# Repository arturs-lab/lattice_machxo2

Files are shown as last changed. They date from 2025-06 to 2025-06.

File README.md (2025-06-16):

# lattice_machxo2
lattice machxo2 256 breakout board

## Power Supply
All four VIO circuits are connected to 3V3 by traces on bottom of the board. 
In this configuration you do not have to populate VIO jumpers, voltaage regulator nor its capacitors.
If you want to use different VIO, cut corresponding trace(s), install jumper(s) and 
VIO voltage regulator and caps.

The 1Ohm resistors on the bottom of the board can be used to measure current draw of IO sections by 
measuring voltage drop on resistors. 0Ohm jumpers can also be installed.

## Oscillator
To use on-board oscillator, install it and jumper pin OSC to CLK.
To use off-board clock source, connect it between CLK and GND pins. 
In this case on-board oscillator does not have to be installed.

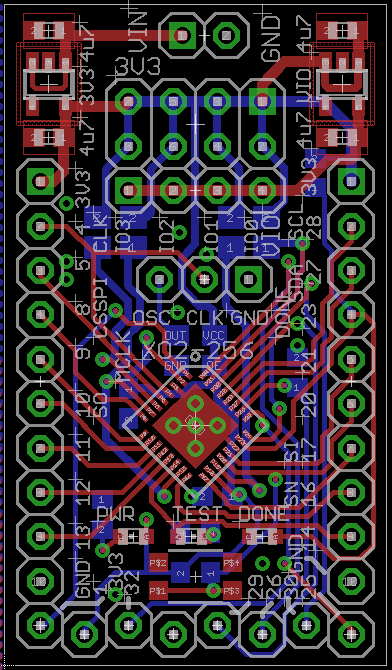
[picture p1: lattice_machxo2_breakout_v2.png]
pcb


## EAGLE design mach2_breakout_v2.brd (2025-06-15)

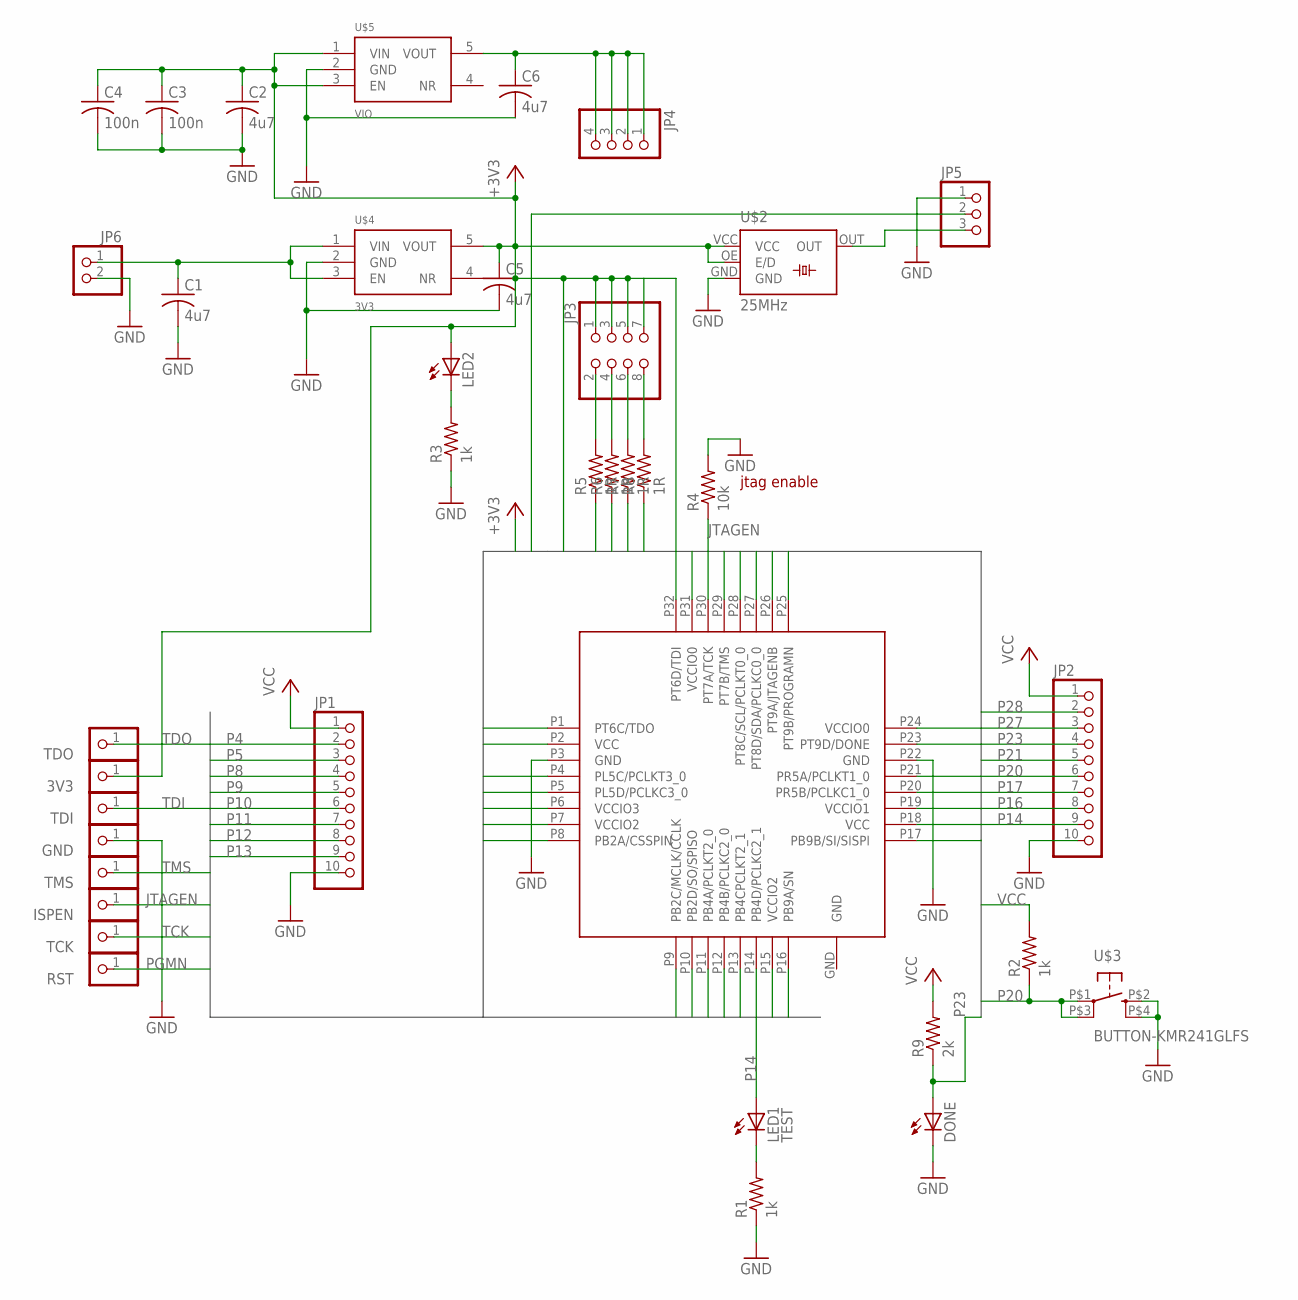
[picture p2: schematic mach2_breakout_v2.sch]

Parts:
3V3: PINHD-1X1; 1X01
C1, C2, C5, C6: 4u7; C0603
C3, C4: 100n; C0603
DONE: LEDCHIPLED_0603; CHIPLED_0603
GND: PINHD-1X1; 1X01
ISPEN: PINHD-1X1; 1X01
JP1, JP2: PINHD-1X10; 1X10
JP3: PINHD-2X4V; 2X04
JP4: PINHD-1X4; 1X04
JP5: PINHD-1X3; 1X03
JP6: PINHD-1X2; 1X02
LED1: TEST; CHIPLED_0603
LED2: LEDCHIPLED_0603; CHIPLED_0603
R1, R2, R3: 1k; R0603
R4: 10k; R0603
R5, R6, R7, R8: 1R; R0805
R9: 2k; R0603
RST: PINHD-1X1; 1X01
TCK: PINHD-1X1; 1X01
TDI: PINHD-1X1; 1X01
TDO: PINHD-1X1; 1X01
TMS: PINHD-1X1; 1X01
U$1: XO2-256; QFN32
U$2: 25MHz; FXO_3225
U$3: BUTTON-KMR241GLFS; PUSHBUTTON-KMR241GLFS
U$4: 3V3; SOT23-5
U$5: VIO; SOT23-5

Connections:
GND: C1.2, C2.2, C3.2, C4.2, C5.2, C6.2, DONE.C, GND.1, JP1.10, JP2.10, JP5.1, JP6.2, R1.1, R3.1, R4.2, U$1.P3 (GND), U$1.P22 (GND), U$2.GND, U$3.P$2 (2), U$3.P$4 (4), U$4.2 (GND), U$5.2 (GND)
JTAGEN: ISPEN.1, R4.1, U$1.P26 (PT9A/JTAGENB)
unnamed: C1.1, JP6.1, U$4.1 (VIN), U$4.3 (EN)
unnamed: JP5.3, U$2.OUT
unnamed: LED1.C, R1.2
unnamed: JP3.8, R8.2
unnamed: LED2.C, R3.2
unnamed: C6.1, JP4.1, JP4.2, JP4.3, JP4.4, U$5.5 (VOUT)
unnamed: JP3.6, R7.2
unnamed: JP3.4, R6.2
unnamed: JP3.2, R5.2
P4: JP1.2, JP5.2, U$1.P4 (PL5C/PCLKT3_0)
P5: JP1.3, U$1.P5 (PL5D/PCLKC3_0)
P8: JP1.4, U$1.P8 (PB2A/CSSPIN)
P9: JP1.5, U$1.P9 (PB2C/MCLK/CCLK)
P10: JP1.6, U$1.P10 (PB2D/SO/SPISO)
P11: JP1.7, U$1.P11 (PB4A/PCLKT2_0)
P12: JP1.8, U$1.P12 (PB4B/PCLKC2_0)
P13: JP1.9, U$1.P13 (PB4CPCLKT2_1)
P14: JP2.9, LED1.A, U$1.P14 (PB4D/PCLKC2_1)
P16: JP2.8, U$1.P16 (PB9A/SN)
P17: JP2.7, U$1.P17 (PB9B/SI/SISPI)
P20: JP2.6, R2.1, U$1.P20 (PR5B/PCLKC1_0), U$3.P$1 (1), U$3.P$3 (3)
P21: JP2.5, U$1.P21 (PR5A/PCLKT1_0)
P23: DONE.A, JP2.4, R9.1, U$1.P23 (PT9D/DONE)
P27: JP2.3, U$1.P27 (PT8D/SDA/PCLKC0_0)
P28: JP2.2, U$1.P28 (PT8C/SCL/PCLKT0_0)
PGMN: RST.1, U$1.P25 (PT9B/PROGRAMN)
TCK: TCK.1, U$1.P30 (PT7A/TCK)
TDI: TDI.1, U$1.P32 (PT6D/TDI)
TDO: TDO.1, U$1.P1 (PT6C/TDO)
TMS: TMS.1, U$1.P29 (PT7B/TMS)
VCC: 3V3.1, C2.1, C3.1, C4.1, C5.1, JP1.1, JP2.1, JP3.1, JP3.3, JP3.5, JP3.7, LED2.A, R2.2, R9.2, U$1.P2 (VCC), U$1.P18 (VCC), U$2.OE (E/D), U$2.VCC, U$4.5 (VOUT), U$5.1 (VIN), U$5.3 (EN)
VCCIO0: R5.1, U$1.P24 (VCCIO0), U$1.P31 (VCCIO0)
VCCIO1: R6.1, U$1.P19 (VCCIO1)
VCCIO2: R7.1, U$1.P7 (VCCIO2), U$1.P15 (VCCIO2)
VCCIO3: R8.1, U$1.P6 (VCCIO3)

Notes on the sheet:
jtag enable

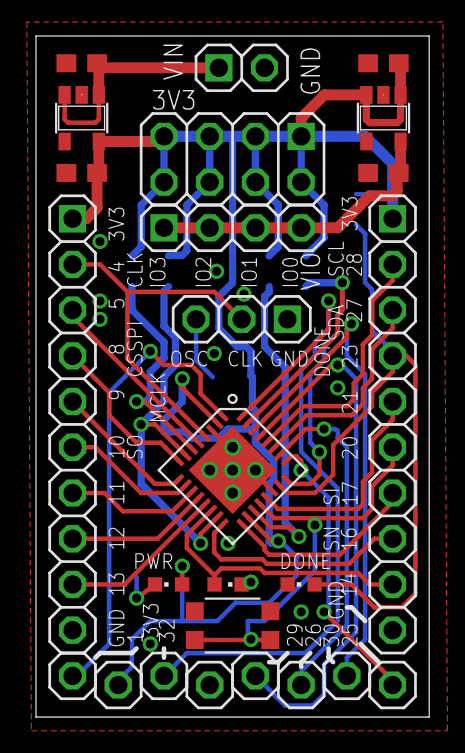
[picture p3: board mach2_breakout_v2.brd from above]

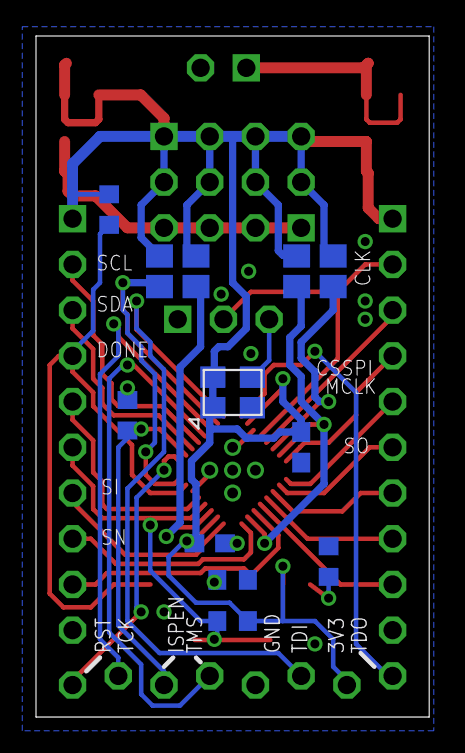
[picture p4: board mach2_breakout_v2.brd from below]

Board: 2 copper layers, 21.8 x 37.8 mm, 37 parts (12 on the bottom side), 37 nets.
